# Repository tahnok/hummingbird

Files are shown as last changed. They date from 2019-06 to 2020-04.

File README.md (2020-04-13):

```
 _   _ _   _ __  __ __  __ ___ _   _  ____ ____ ___ ____  ____  
| | | | | | |  \/  |  \/  |_ _| \ | |/ ___| __ )_ _|  _ \|  _ \ 
| |_| | | | | |\/| | |\/| || ||  \| | |  _|  _ \| || |_) | | | |
|  _  | |_| | |  | | |  | || || |\  | |_| | |_) | ||  _ <| |_| |
|_| |_|\___/|_|  |_|_|  |_|___|_| \_|\____|____/___|_| \_\____/ 
```



A lightweight device for capture altitude and other data from a kite

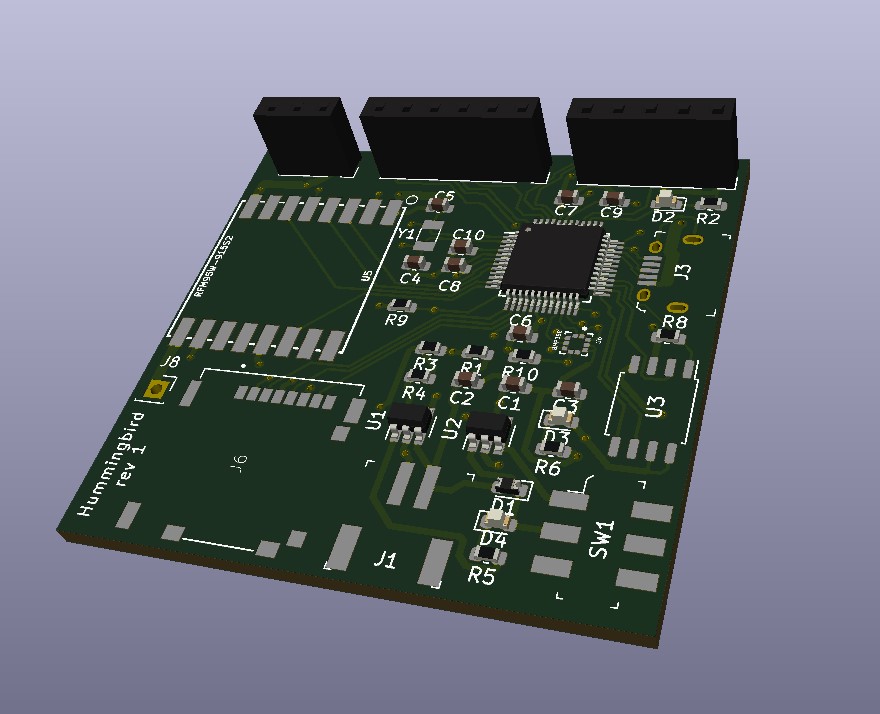
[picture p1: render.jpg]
render of board


**r1 status:** DO NOT PLUG IN A BATTERY

## References

 - BMP388, microSD and Slide switch footprint from Digikey
 - [RFM69 Footprint](https://github.com/benwis/SparkFun-Kicad-Libraries/blob/master/SparkFun-RF.pretty/RFM69HCW-XXXS2.kicad_mod)

## Building

 The `gerbers` folder has a zip file if you want to order your own PCB.

 There is a `bom.csv` that contains all the parts and digikey part numbers you need

 There's also an `interactive_bom.html` that is from the excellent [InteractiveHtmlBom](https://github.com/openscopeproject/InteractiveHtmlBom) plugin

 ## Known Issues

 ### Rev 1

  1. **Battery connector is wired backwards**
  1. microSD footprint is backwards, so it is un-usable
  1. Battery and battery charging to do not work. I plugged one in, immediatly smelled burning. Current theory is that I forgot a current limiting resistor on the LDO's EN pin, so too much current from battery (but not from USB).

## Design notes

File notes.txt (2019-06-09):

TODO

 - assign arduino pin numbers
 - oscilator crystal selection / caps
 - replace LDO with higher amp one
 - figure out if chip selects need pull ups
 - read lora datasheet for pins

----

how do I assign pins so that I can use them in arduino? -> variants.h / variants.cpp

how does sercom work?
seems like pins can be use in SERCOM or SERCOM_ALT mode, each pin has 2 sercom it can belong to.
Can pads overlap? no, one per sercom
what is a pad? set of 4 pins for each SERCOM

https://learn.adafruit.com/using-atsamd21-sercom-to-add-more-spi-i2c-serial-ports/creating-a-new-serial

page 28 of datasheet has pin table

how many SPIs do I need?

 - what is each SPI mode that I need for my devices?
  - BMP388: active low, mode 0
  - SD Card: active low, mode 0 (maybe mode 1?)
  - LoRa: The SPI interface gives access to the configuration register via a synchronous full-duplex protocol corresponding to
CPOL = 0 and CPHA = 0 (pg75 of RFM9x manual), also active low
  - SPI flash: SPI bus operation Mode 0 (0,0) and 3 (1,1) are supporte

FLASH

 do I need to do anything with hold or reset? what about write protect? -> yes, hold high according to data sheet

SERCOM and USB? -> it's fine, they are seperate things

available sercoms:

 - sercom 0 (4 pads) -> microSD
 - sercom 1 (4 pads) -> SPI flash
 - sercom 2 (4 pads) -> BMP388
 - sercom 3 (2 pads) -> I2C breakout
 - sercom 4 (4 pads) -> LoRa
 - sercom 5 (4 pads) -> Serial

battery monitoring

ref: https://learn.adafruit.com/adafruit-feather-32u4-basic-proto/power-management#measuring-battery-4-9

https://jeelabs.org/2013/05/16/measuring-the-battery-without-draining-it/

do I add mosfet in exchange for 0 power draw? or let the battery slowly discharge

chip select pullups

https://hackaday.com/2014/11/25/better-spi-bus-design/

"best" practice is yes when shared. SPI flash has it anyway on feather m0 express though

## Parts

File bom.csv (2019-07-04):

Item | Qty | Reference(s) | Value | LibPart | Footprint | Datasheet | DigiKey Part Number | Field4 | Field5 | Field6 | Field7 | Field8
1 | 3 | C1, C2, C3 | 10uF | Device:C_Small | footprints:C_0603_1608Metric | ~ | 1276-1119-1-ND
2 | 2 | C4, C5 | 22pF | Device:C_Small | footprints:C_0603_1608Metric | ~ | 478-1167-1-ND
3 | 3 | C6, C7, C8 | 100nF | Device:C_Small | footprints:C_0603_1608Metric | ~ | 311-1088-1-ND
4 | 2 | C9, C10 | 1uF | Device:C_Small | footprints:C_0603_1608Metric | ~ | 1276-1182-1-ND
5 | 1 | D1 | D_Schottky | Device:D_Schottky_Small | footprints:D_0603_1608Metric | ~ | 478-7798-1-ND
6 | 3 | D2, D3, D4 | LED | Device:LED | footprints:LED_0603_1608Metric | ~ | SML-D12U1WT86CT-ND
9 | 1 | J3 | USB_B_Micro | symbols:USB_B_Micro | footprints:USB_Micro_B_Female_10118194-0001LF | ~ | 609-4618-1-ND
12 | 1 | J6 | microSD | symbols:microSD | microSD_503182-1852:MOLEX_503182-1852 | https://www.molex.com/pdm_docs/sd/5031821852_sd.pdf | WM12834CT-ND | MICRO SD NORMAL ULTRALOWPRO8CKTE | Molex | None | WM12834CT-ND | https://www.digikey.com/product-detail/en/molex/5031821852/WM12834CT-ND/5823232
16 | 2 | R1, R3 | 100k | Device:R_Small | footprints:R_0603_1608Metric | ~ | RR08P100KDCT-ND
17 | 3 | R2, R5, R6 | 1k | Device:R_Small | footprints:R_0603_1608Metric | ~ | RHM1.0KDCT-ND
18 | 5 | R4, R7, R8, R9, R10 | 10k | Device:R_Small | footprints:R_0603_1608Metric | ~ | RHM10KADCT-ND
19 | 1 | SW1 | SW_DPDT_x2 | Switch:SW_DPDT_x2 | footprints:Switch_Slide_JS202011SCQN |  | 401-2002-1-ND
20 | 1 | U1 | MCP73831-2-OT | Battery_Management:MCP73831-2-OT | footprints:SOT-23-5 | http://ww1.microchip.com/downloads/en/DeviceDoc/20001984g.pdf | MCP73831T-2ACI/OTCT-ND
21 | 1 | U2 | AP2112K-3.3 | Regulator_Linear:AP2112K-3.3 | footprints:SOT-23-5 | https://www.diodes.com/assets/Datasheets/AP2112.pdf | AP2112K-3.3TRG1DICT-ND
22 | 1 | U3 | W25Q64JVSSIM | symbols:W25Q64JVSSIM | footprints:SOIC-8_5.23x5.23mm_P1.27mm | http://www.winbond.com/resource-files/w25q64jv%20revj%2003272018%20plus.pdf | W25Q64JVSSIMCT-ND
23 | 1 | U4 | ATSAMD21G18A-AUT | symbols:ATSAMD21G18A-AUT | footprints:TQFP-48_7x7mm_P0.5mm | http://ww1.microchip.com/downloads/en/DeviceDoc/SAMD21-Family-DataSheet-DS40001882D.pdf | ATSAMD21G18A-AUTCT-ND
24 | 1 | U5 | RFM95W-915S2 | RF_Module:RFM95W-915S2 | footprints:RFM69HCW-XXXS2 | https://www.hoperf.com/data/upload/portal/20181127/5bfcbea20e9ef.pdf | RFM95W-915S2-ND
25 | 1 | U6 | BMP388 | symbols:BMP388 | BMP388:PQFN50P200X200X80-10N | https://ae-bst.resource.bosch.com/media/_tech/media/datasheets/BST-BMP388-DS001.pdf | 828-1079-1-ND | 828-1079-1-ND | P-Sensor SPI I2C 1, 25 Bar SMD | https://www.digikey.com/product-detail/en/bosch-sensortec/BMP388/828-1079-1-ND/8322640 | BMP388 | WFLGA-10 Bosch Tools
26 | 1 | Y1 | 32.768 Hz | Device:Crystal | footprints:Crystal_SMD_3215-2Pin_3.2x1.5mm | https://abracon.com/Resonators/ABS07.pdf | 535-9542-1-ND

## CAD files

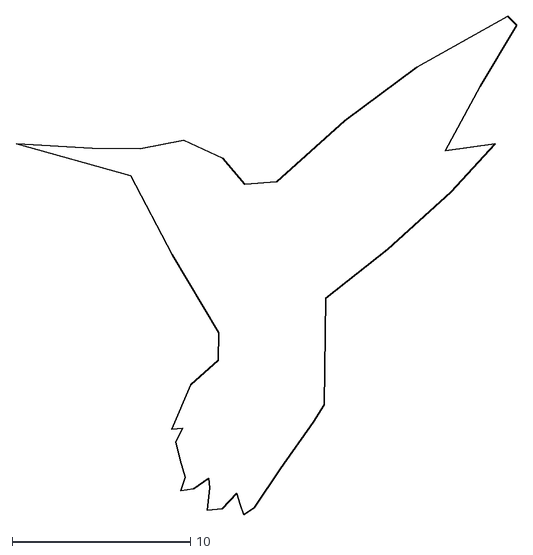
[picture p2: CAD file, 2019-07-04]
art/hummingbird.dxf
28.0 x 28.0

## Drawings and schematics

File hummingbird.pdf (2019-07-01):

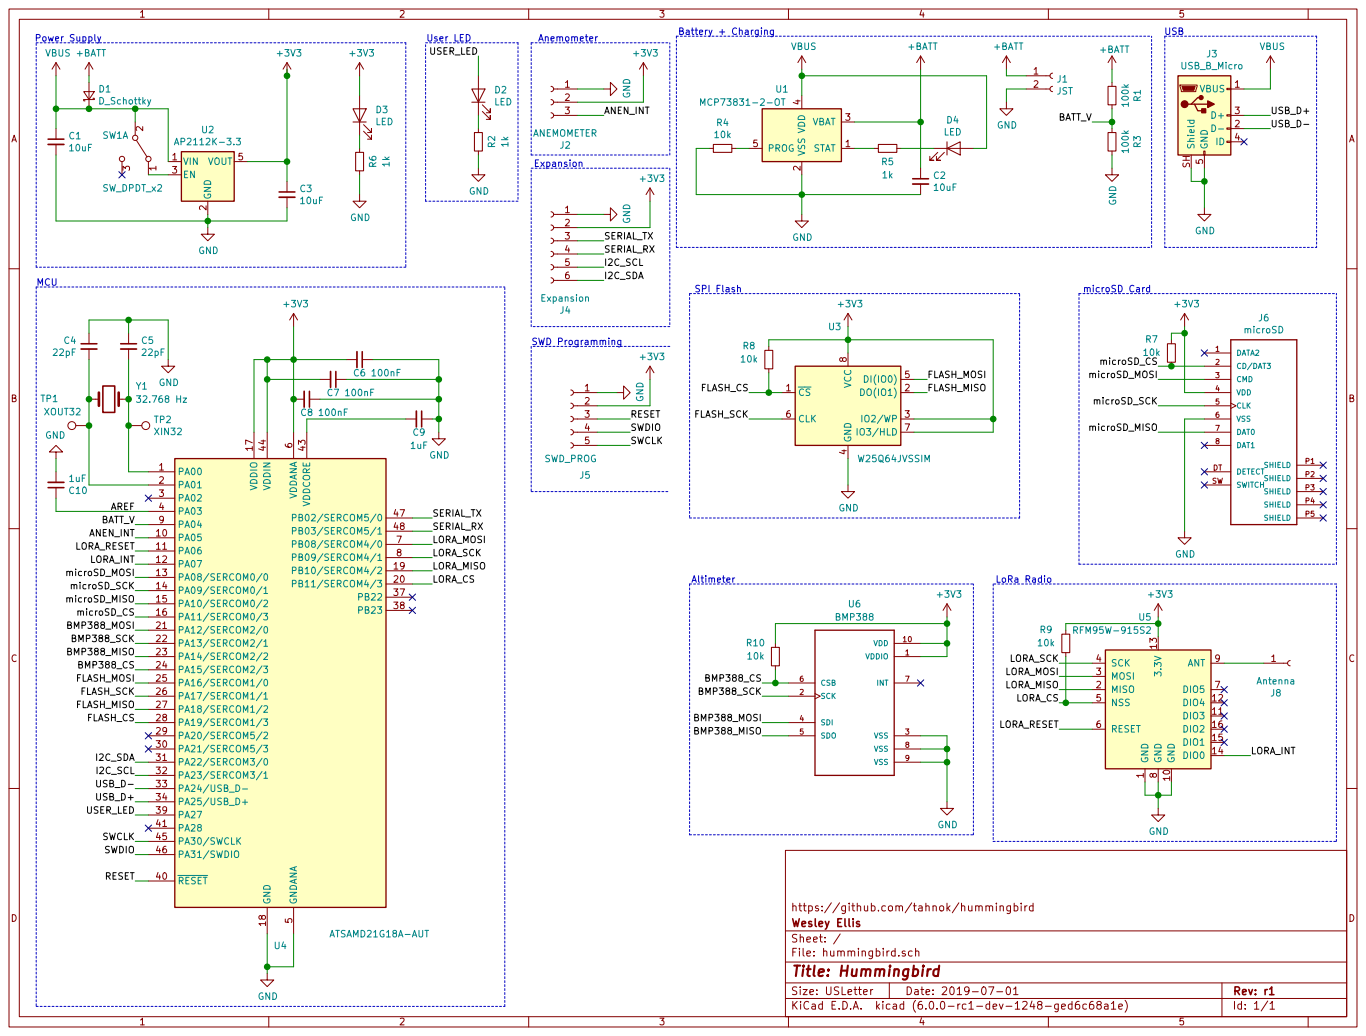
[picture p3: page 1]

4 PROG 5 U1 MCP73831-2-OT VBUS +BATT D4

1 GND 10 DIO3 11 DIO4 12 3.3V 13 DIO0 14 DIO1 15 DIO2 16 MISO 2 MOSI 3 SCK 4 NSS 5 RESET 6 DIO5 7 GND

https://github.com/tahnok/hummingbird
File: hummingbird.sch Sheet: / Wesley Ellis

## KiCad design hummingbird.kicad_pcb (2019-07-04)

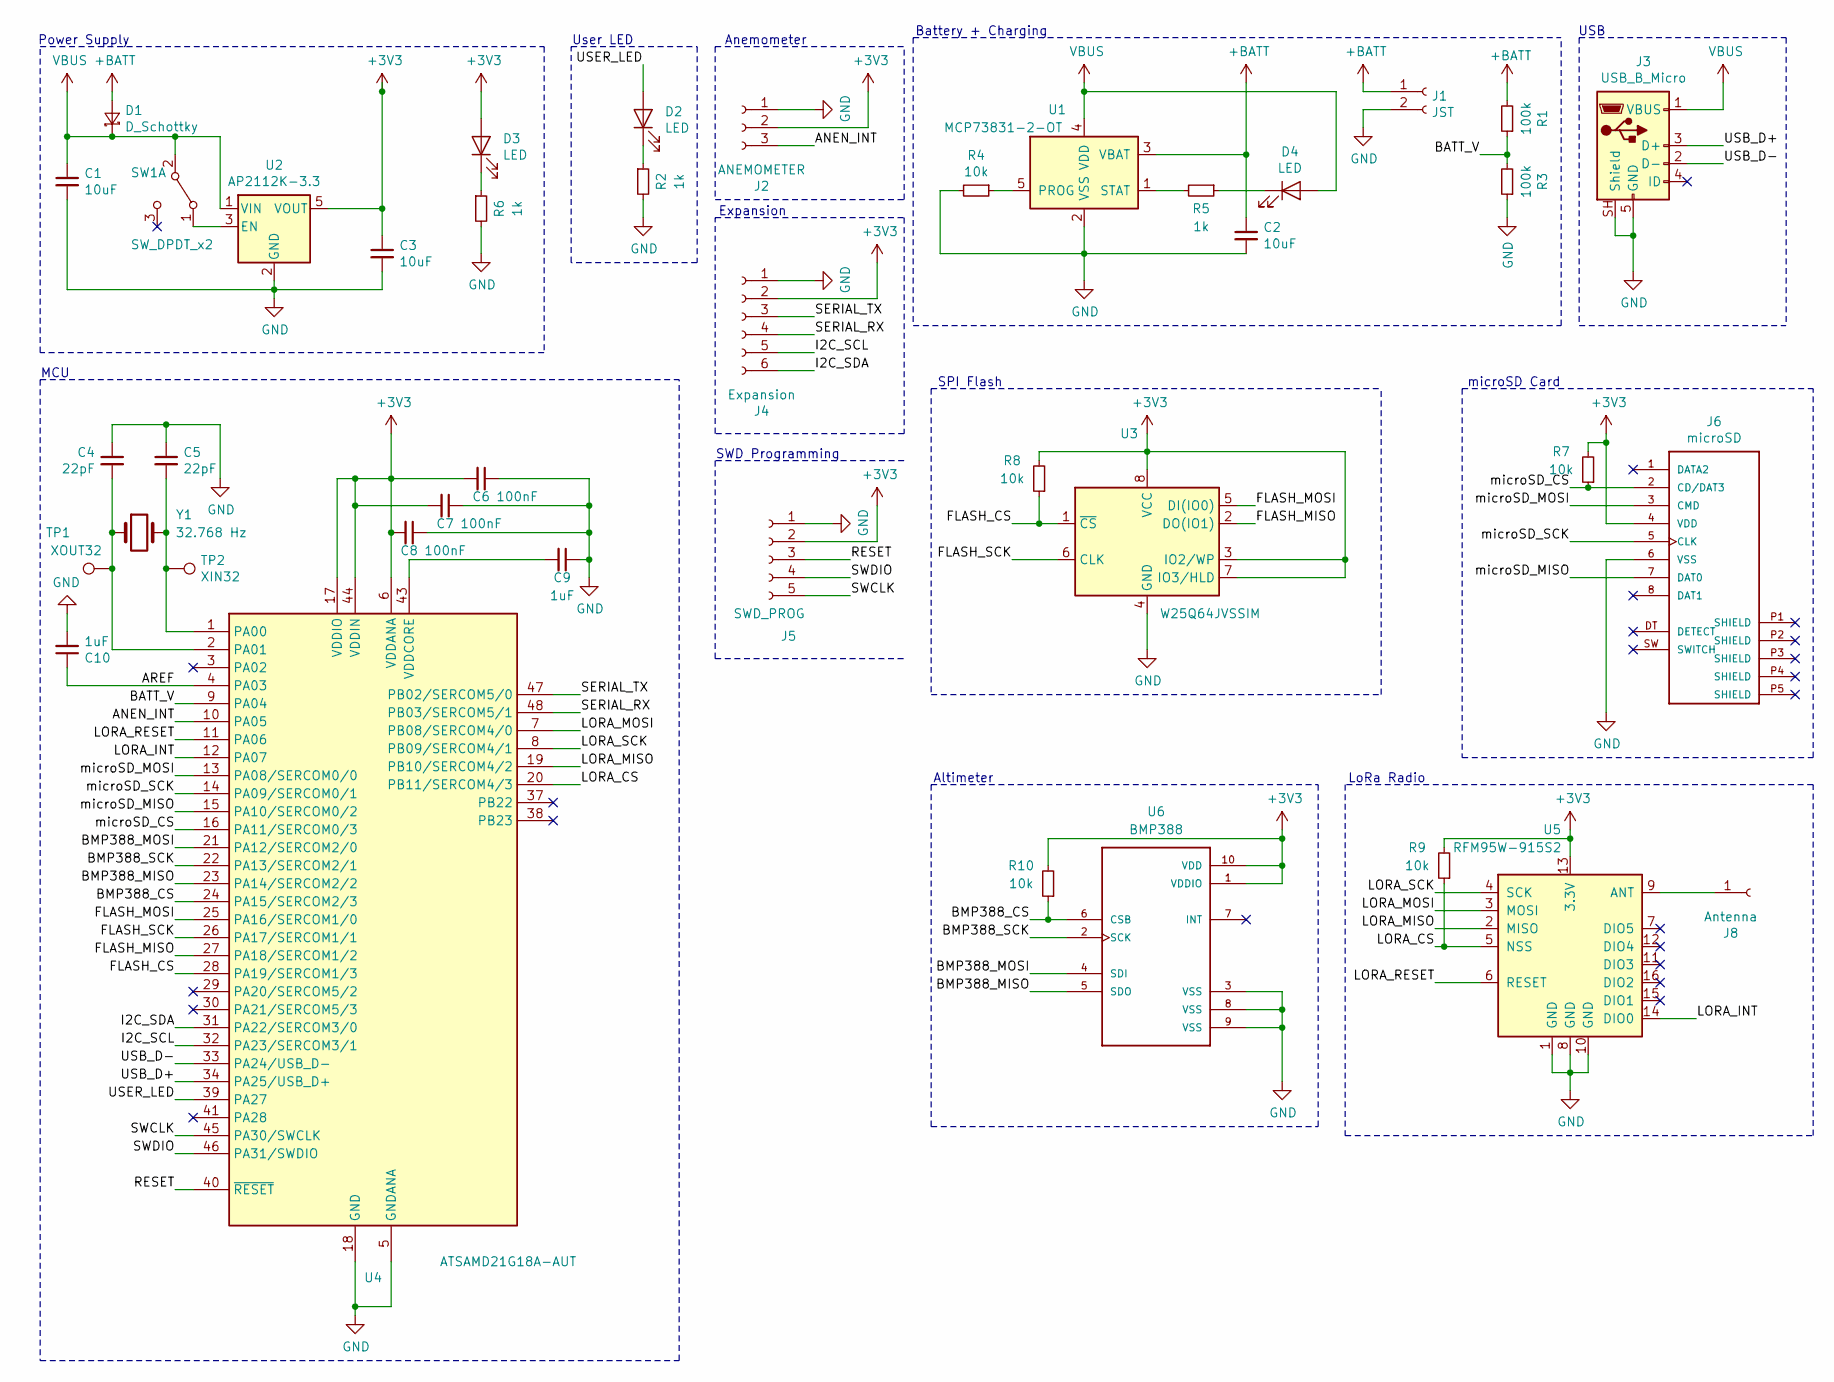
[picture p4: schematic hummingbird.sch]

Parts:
C1, C2, C3: 10uF; C_0603_1608Metric; DigiKey Part Number 1276-1119-1-ND
C4, C5: 22pF; C_0603_1608Metric; DigiKey Part Number 478-1167-1-ND
C6, C7, C8: 100nF; C_0603_1608Metric; DigiKey Part Number 311-1088-1-ND
C9, C10: 1uF; C_0603_1608Metric; DigiKey Part Number 1276-1182-1-ND
D1: D_Schottky; D_0603_1608Metric; DigiKey Part Number 478-7798-1-ND
D2, D3, D4: LED; LED_0603_1608Metric; DigiKey Part Number SML-D12U1WT86CT-ND
J1: JST; PinHeader_2x1mm_P2mm_SMD_RA; DigiKey Part Number 455-1749-1-ND
J2: ANEMOMETER; PinSocket_1x03_P2.54mm_Vertical
J3: USB_B_Micro; USB_Micro_B_Female_10118194-0001LF; DigiKey Part Number 609-4618-1-ND
J4: Expansion; PinSocket_1x06_P2.54mm_Vertical
J5: SWD_PROG; PinSocket_1x05_P2.54mm_Vertical
J6: microSD; MOLEX_503182-1852; DigiKey Part Number WM12834CT-ND
J8: Antenna; PinSocket_1x01_P2.54mm_Vertical
R1, R3: 100k; R_0603_1608Metric; DigiKey Part Number RR08P100KDCT-ND
R2, R5, R6: 1k; R_0603_1608Metric; DigiKey Part Number RHM1.0KDCT-ND
R4, R7, R8, R9, R10: 10k; R_0603_1608Metric; DigiKey Part Number RHM10KADCT-ND
SW1: SW_DPDT_x2; Switch_Slide_JS202011SCQN; DigiKey Part Number 401-2002-1-ND
TP1: XOUT32; TestPoint_Pad_D1.0mm
TP2: XIN32; TestPoint_Pad_D1.0mm
U1: MCP73831-2-OT; SOT-23-5; DigiKey Part Number MCP73831T-2ACI/OTCT-ND
U2: AP2112K-3.3; SOT-23-5; DigiKey Part Number AP2112K-3.3TRG1DICT-ND
U3: W25Q64JVSSIM; SOIC-8_5.23x5.23mm_P1.27mm; DigiKey Part Number W25Q64JVSSIMCT-ND
U4: ATSAMD21G18A-AUT; TQFP-48_7x7mm_P0.5mm; DigiKey Part Number ATSAMD21G18A-AUTCT-ND
U5: RFM95W-915S2; RFM69HCW-XXXS2; DigiKey Part Number RFM95W-915S2-ND
U6: BMP388; PQFN50P200X200X80-10N; DigiKey Part Number 828-1079-1-ND
Y1: 32.768 Hz; Crystal_SMD_3215-2Pin_3.2x1.5mm; DigiKey Part Number 535-9542-1-ND

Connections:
+3V3: C3.1, C6.2, C7.2, C8.2, D3.2 (A), J2.2, J4.2, J5.2, J6.4 (VDD), R7.2, R8.2, R9.2, R10.2, U2.5 (VOUT), U3.3 (IO2/WP), U3.7 (IO3/HLD), U3.8 (VCC), U4.6 (VDDANA), U4.17 (VDDIO), U4.36 (VDDIO), U4.44 (VDDIN), U5.13 (3.3V), U6.1 (VDDIO), U6.10 (VDD)
+BATT: C2.1, D1.2 (A), J1.1, R1.2, U1.3 (VBAT)
/ANEN_INT: J2.3, U4.10 (PA05)
/AREF: C10.1, U4.4 (PA03)
/BATT_V: R1.1, R3.2, U4.9 (PA04)
/BMP388_CS: R10.1, U4.24 (PA15/SERCOM2/3), U6.6 (CSB)
/BMP388_MISO: U4.23 (PA14/SERCOM2/2), U6.5 (SDO)
/BMP388_MOSI: U4.21 (PA12/SERCOM2/0), U6.4 (SDI)
/BMP388_SCK: U4.22 (PA13/SERCOM2/1), U6.2 (SCK)
/FLASH_CS: R8.1, U3.1 (~CS), U4.28 (PA19/SERCOM1/3)
/FLASH_MISO: U3.2 (DO(IO1)), U4.27 (PA18/SERCOM1/2)
/FLASH_MOSI: U3.5 (DI(IO0)), U4.25 (PA16/SERCOM1/0)
/FLASH_SCK: U3.6 (CLK), U4.26 (PA17/SERCOM1/1)
/I2C_SCL: J4.5, U4.32 (PA23/SERCOM3/1)
/I2C_SDA: J4.6, U4.31 (PA22/SERCOM3/0)
/LORA_CS: R9.1, U4.20 (PB11/SERCOM4/3), U5.5 (NSS)
/LORA_INT: U4.12 (PA07), U5.14 (DIO0)
/LORA_MISO: U4.19 (PB10/SERCOM4/2), U5.2 (MISO)
/LORA_MOSI: U4.7 (PB08/SERCOM4/0), U5.3 (MOSI)
/LORA_RESET: U4.11 (PA06), U5.6 (RESET)
/LORA_SCK: U4.8 (PB09/SERCOM4/1), U5.4 (SCK)
/RESET: J5.3, U4.40 (~RESET)
/SERIAL_RX: J4.4, U4.48 (PB03/SERCOM5/1)
/SERIAL_TX: J4.3, U4.47 (PB02/SERCOM5/0)
/SWCLK: J5.5, U4.45 (PA30/SWCLK)
/SWDIO: J5.4, U4.46 (PA31/SWDIO)
/USB_D+: J3.3 (D+), U4.34 (PA25/USB_D+)
/USB_D-: J3.2 (D-), U4.33 (PA24/USB_D-)
/USER_LED: D2.2 (A), U4.39 (PA27)
/microSD_CS: J6.2 (CD/DAT3), R7.1, U4.16 (PA11/SERCOM0/3)
/microSD_MISO: J6.7 (DAT0), U4.15 (PA10/SERCOM0/2)
/microSD_MOSI: J6.3 (CMD), U4.13 (PA08/SERCOM0/0)
/microSD_SCK: J6.5 (CLK), U4.14 (PA09/SERCOM0/1)
GND: C1.2, C2.2, C3.2, C4.1, C5.1, C6.1, C7.1, C8.1, C9.1, C10.2, J1.2, J2.1, J3.5 (GND), J3.SH (Shield), J4.1, J5.1, J6.6 (VSS), R2.2, R3.1, R4.2, R6.2, U1.2 (VSS), U2.2 (GND), U3.4 (GND), U4.5 (GNDANA), U4.18 (GND), U4.35 (GND), U4.42 (GND), U5.1 (GND), U5.8 (GND), U5.10 (GND), U6.3 (VSS), U6.8 (VSS), U6.9 (VSS)
unnamed: C4.2, TP1.1, U4.2 (PA01), Y1.1
unnamed: C5.2, TP2.1, U4.1 (PA00), Y1.2
unnamed: C9.2, U4.43 (VDDCORE)
unnamed: D2.1 (K), R2.1
unnamed: D3.1 (K), R6.1
unnamed: D4.1 (K), R5.1
unnamed: J8.1, U5.9 (ANT)
unnamed: R4.1, U1.5 (PROG)
unnamed: R5.2, U1.1 (STAT)
unnamed: SW1.1 (A), U2.3 (EN)
VBUS: C1.1, D1.1 (K), D4.2 (A), J3.1 (VBUS), SW1.2 (B), U1.4 (VDD), U2.1 (VIN)

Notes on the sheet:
Power Supply
Battery + Charging
Altimeter
microSD Card
SPI Flash
LoRa Radio
USB
User LED
Anemometer
Expansion
SWD Programming
MCU

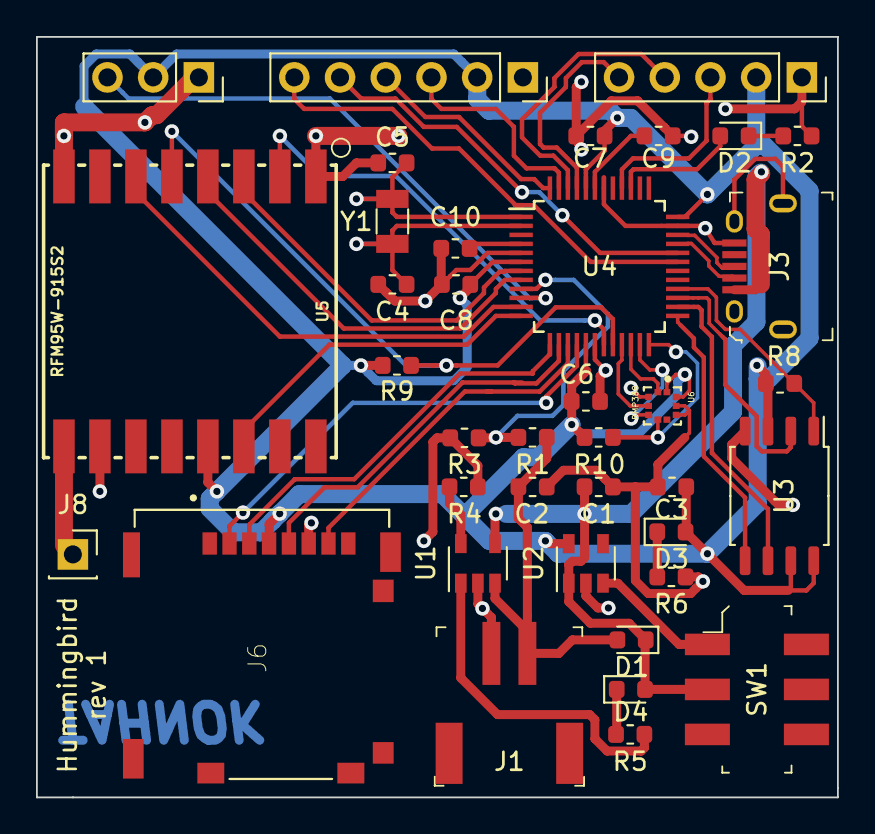
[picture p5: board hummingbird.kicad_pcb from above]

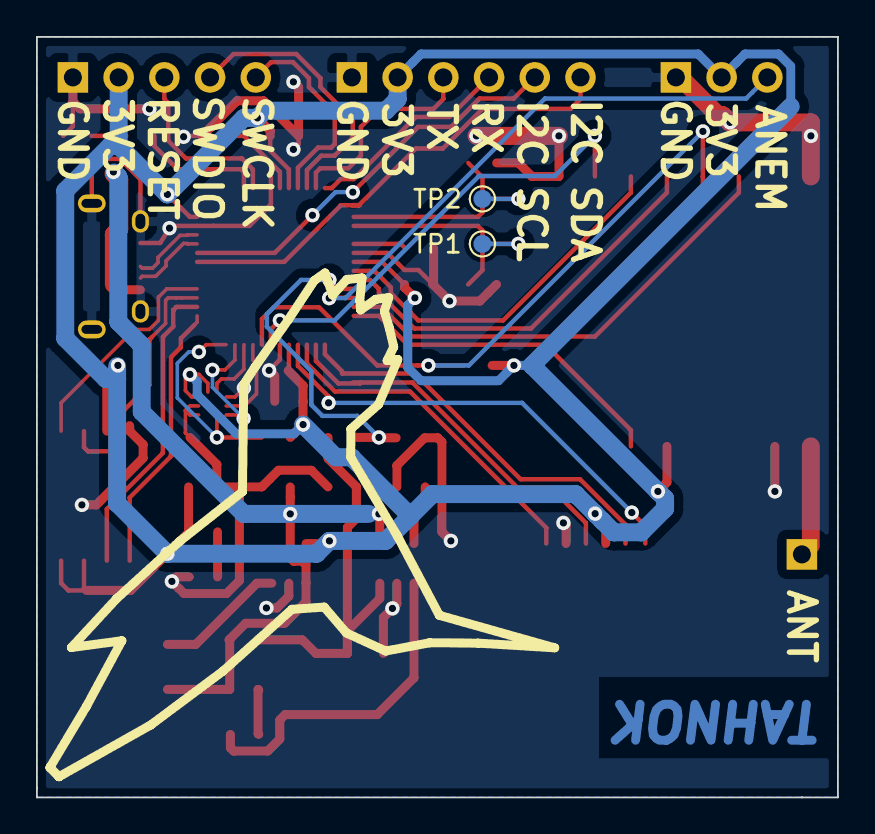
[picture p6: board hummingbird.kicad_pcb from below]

Board: 2 copper layers, 44.5 x 42.2 mm, 40 parts (2 on the bottom side), 45 nets.

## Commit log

2019-06-02 start adding wires
    [hummingbird.sch]
2019-06-02 add power, charging and bmp388
    [hummingbird.sch, power.sch]
2019-06-03 spi flash, lora and microsd added
    [hummingbird.sch]
2019-06-09 add sercom labels, wire up SD card and BMP388
    [hummingbird.sch]
2019-06-09 Add LoRa Spi connections
    [hummingbird.sch]
2019-06-09 finish spi wiring, add connectors
    [hummingbird.sch]
2019-06-13 new voltage regulator, add pullups on CS, fix BMP388 CS
    [hummingbird.sch]
2019-06-14 add crystal and capacitors
    [hummingbird.sch]
2019-06-14 renaming things, add SOIC prog clip header
    [hummingbird.sch]
2019-06-14 schematic first draft
    [hummingbird.sch]
2019-06-14 actually finish schematic and connect pins
    [hummingbird.sch]
2019-06-14 start adding footprints
    [hummingbird.sch]
2019-06-15 add bmp388, SOICbyte and microSD footprint
    [hummingbird.sch]
2019-06-15 finish selecting footprints
2019-06-15 copy all footprints to repo
    [hummingbird.sch]
2019-06-17 Add digikey part numbers
    [hummingbird.sch]
2019-06-17 First attempt at PCB
    [hummingbird.kicad_pcb]
2019-06-21 remove SMA and some routing
    [hummingbird.kicad_pcb, hummingbird.sch]
2019-06-22 rough placement (gonna try the autorouter)
    [hummingbird.kicad_pcb]
2019-06-29 remove SOICbyte, start layout over, rejigger pinouts
    [hummingbird.kicad_pcb, hummingbird.sch, noname.kicad_pcb]
2019-07-01 0 unrouted!
    [noname.kicad_pcb]
2019-07-01 Added labels
    [noname.kicad_pcb]
2019-07-01 add hummingbird drawing
    [hummingbird.dxf, noname.kicad_pcb]
2019-07-01 move PCB to right file name
    [hummingbird.kicad_pcb, noname.kicad_pcb]
2019-07-01 Add schematic rev and date
    [hummingbird.sch]
2019-07-04 add gerbers for r1 production run!
    [hummingbird-B.Cu.gbr, hummingbird-B.Mask.gbr, hummingbird-B.Paste.gbr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]
2019-07-04 add bom and interactive bom
    [bom.csv]
2019-07-04 Actual BOM
    [bom.csv]
